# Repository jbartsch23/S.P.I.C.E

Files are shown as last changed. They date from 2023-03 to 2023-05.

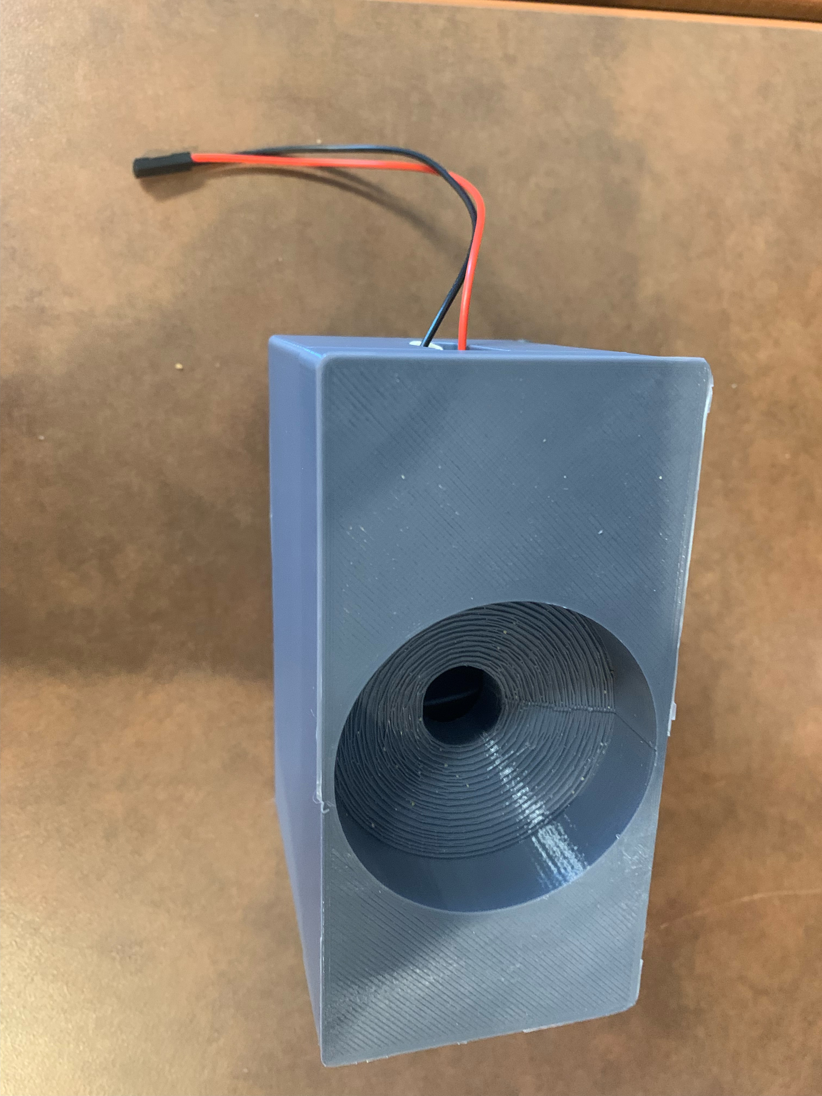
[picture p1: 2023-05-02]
Pictures/housing.jpeg

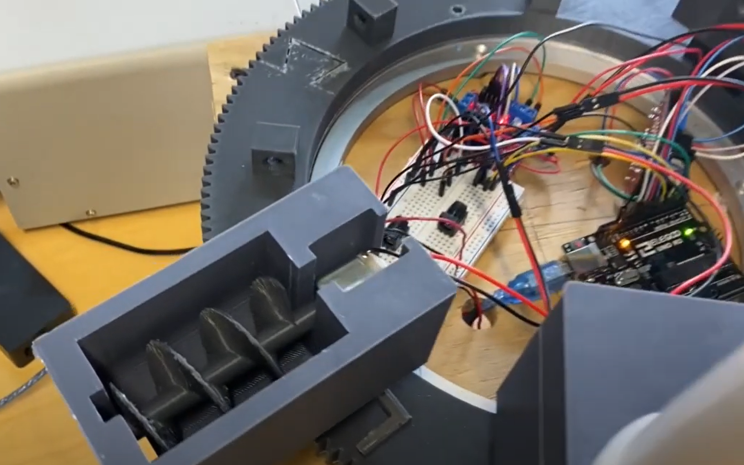
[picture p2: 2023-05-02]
Pictures/circuitry.png

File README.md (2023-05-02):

# S.P.I.C.E.
Directory Guide:
- 3D Models: All inventor files as well as stl files for 3D parts
- Pictures: A collection of close-up pictures of the system
- Presentations: All presentations throughout the semester (Proposal, CDR, Final)
- Reports: All reports throughout the semester (Proposal, CDR, Final)
- TeamMeetings: A collection of every weekly meeting held by Dr.M, TA Karl Ott, and the team
- TeamNotebooks: Notebook scans from each team member throughout the semester
- bin: Directory for all class objects generated from src
- motor_control: The final Arduino code used to operate the SPICE platform
- src: Directory contains all JavaFX and UI elements

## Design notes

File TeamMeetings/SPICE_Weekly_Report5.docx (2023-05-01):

WEEKLY REPORT and MEETING AGENDA

Report #: 5 Project Name: SPICE

Date: 4/4/2023 Prepared by: Carlos Zapata III

Agenda for the meeting

1. Print shop update (Over-Estimated Time)
2. Database progress

Overall accomplishments since last meeting

1. Printed prototype housing at FEDC
2. More prints requested
3. Established database connection

Tasks completed by each team member since last meeting

Task description | Assigned to | Completed?
Received housing and lid printed from FEDC | Carlos | Yes
SQL Server setup, connection between database and UI | JP/Caleb/Carlos | Yes

Plans for next period

1. Improve model designs and send to FEDC to print
2. Finalize database

Task assignment per team member (to be completed before the next meeting)

Task description | Assigned to
Send second set of prints to FEDC | Caleb/Carlos
Finish designing and implement database | JP/Caleb/Carlos
Implement reliable communication between Arduino and Raspberry Pi | Kile/Caleb

Project management status

Minutes from previous meeting

Meeting Minutes (March 29th):

- Print Shop update:
- Dr.M: Tell me about print shop
- Caleb: Originally wanted to print with personal printer, will now be using FEDC to get prints
- Dr.M: One print per day, will take a week, need to get that printed as fast as possible
  - Bottlenecking at 3D printing
- Local SQL Database
- JP: Looking to use local database - Easier to query database
  - Microsoft SQL server
- Dr.M: Demonstrate that system is able to perform recipe function
- Progress with motors and Arduino
- Kile: Motors are working and can be turned off and on with Pi
  - Having trouble with controlling motor speed
- Dr.M: Sounds good
- Troubles with 3D printing
  - Caleb: Taking a long time
  - Dr.M & Karl: Focus on getting functionality with one or two, and then work in parallel
- Dr.M: Might have better 3D printers that work faster
  - Go to shop as soon as possible
- Thinking differently about solutions
- Dr.M: Might want to look for printing outside of A&M
- Dr.M: Keep us updated, think about alternatives

Weekly Report Form. CSCE 483 Computer System Design

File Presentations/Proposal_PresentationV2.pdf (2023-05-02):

A creative solution for assisted cooking

# The Problem

61 Million | 37 Million

01 | Americans Live

100% of People
need to eat

# Needs Statement

### In a country where one in four adults have some form of motor impairment and older adults are more likely to live alone, there’s a serious need for tools that can make tasks easier for motor impaired adults

# The Mission

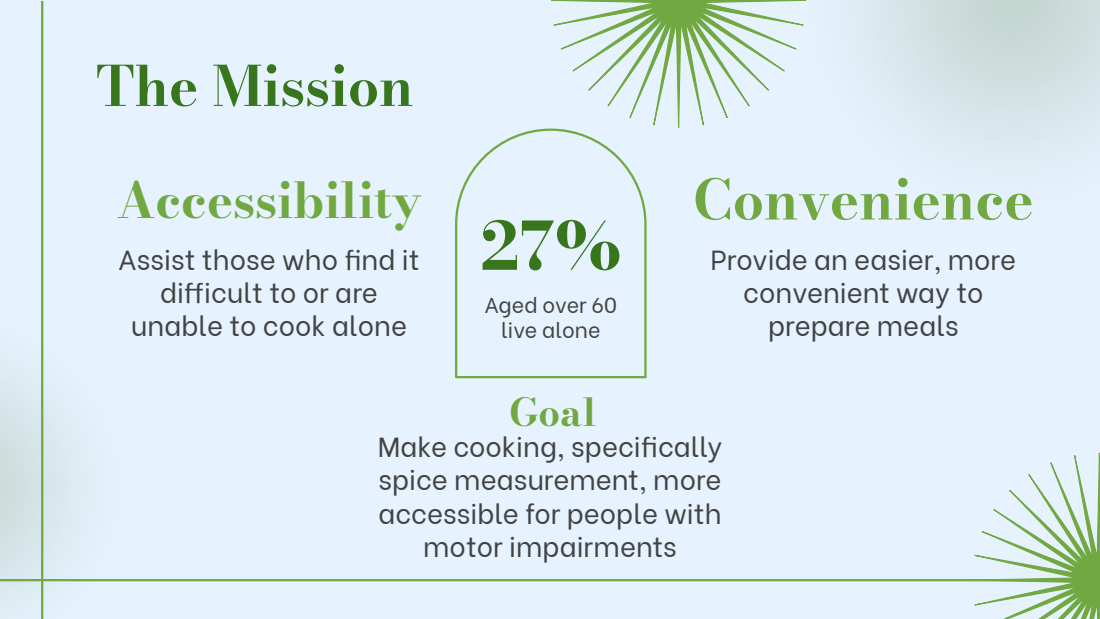
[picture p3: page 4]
Goal; Aged over 60 live alone; Convenience

Accessibility
Assist those who find it
difficult to or are
unable to cook alone

Provide an easier, more
convenient way to
prepare meals

Make cooking, specifically
spice measurement, more
accessible for people with
motor impairments

# Goals and Objectives

Accessibility
S.P.I.C.E. aims to make
cooking accessible for
everyone
Easy Maintenance
S.P.I.C.E. will be easy to use and

Convenience
Providing an exceptionally
convenient way of
preparing meals

# Literature Review

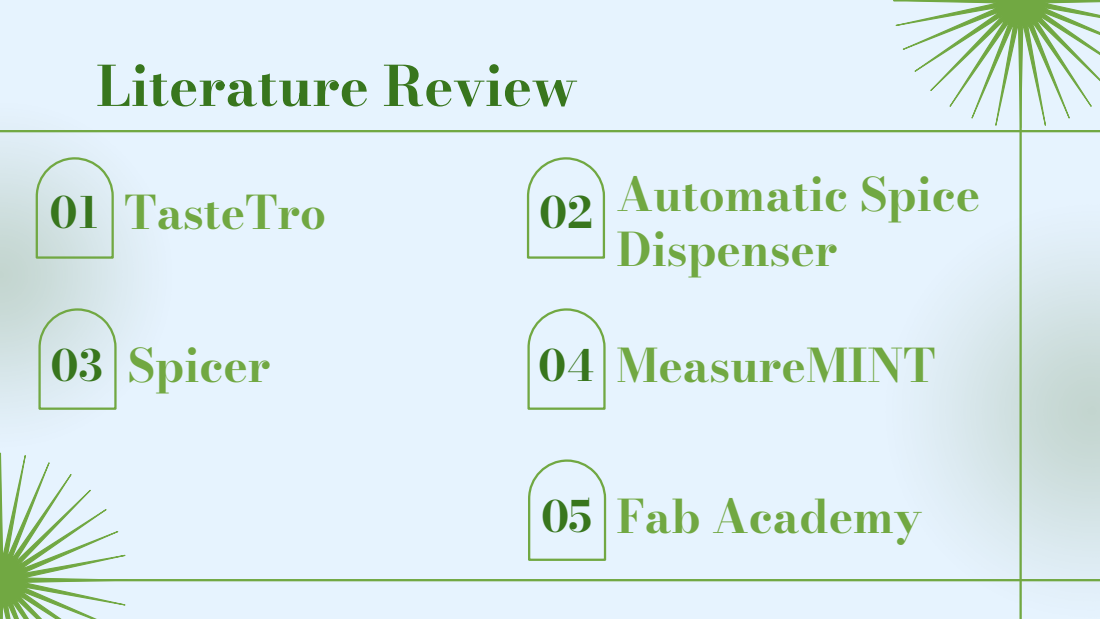
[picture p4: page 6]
TasteTro; Automatic Spice; Dispenser; Spicer; MeasureMINT; 05 Fab Academy

- Commercially advertised since Jan. 2018
- Simple 3-button interface, unique spice storage and distribution
- Operates on predetermined recipes; S.P.I.C.E. intends to consider

- Doesn’t incorporate UI; S.P.I.C.E. intends to

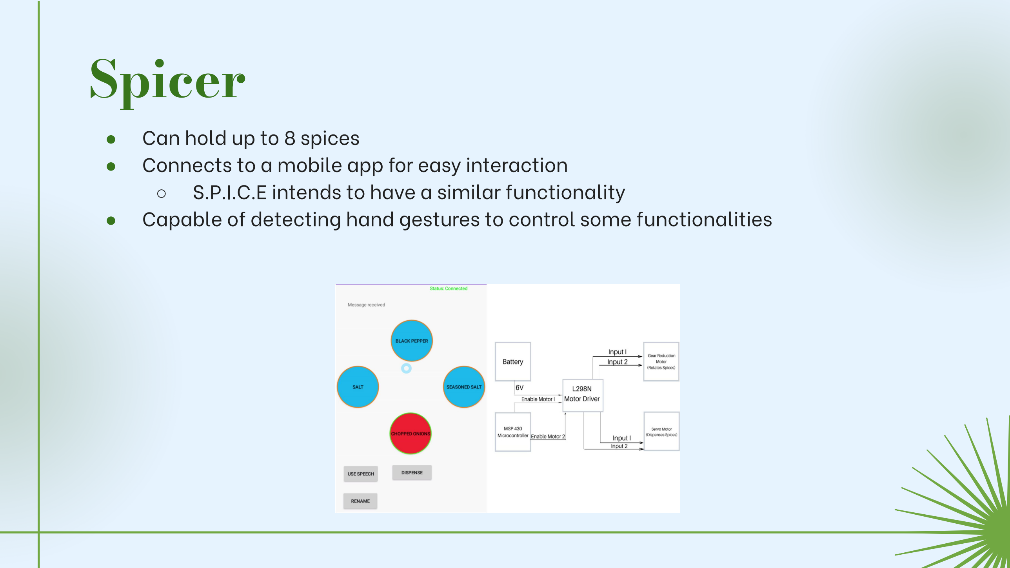
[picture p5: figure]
● Can hold up to 8 spices; Spicer

- Connects to a mobile app for easy interaction
- S.P.I.C.E intends to have a similar functionality
- Capable of detecting hand gestures to control some functionalities

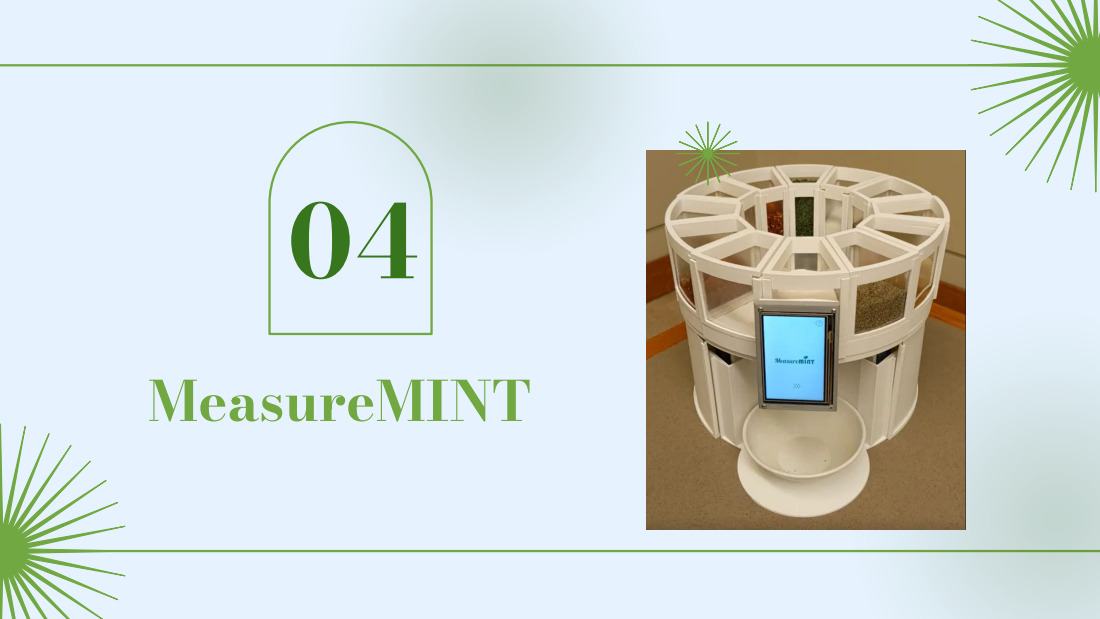
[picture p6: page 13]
MeasureMINT

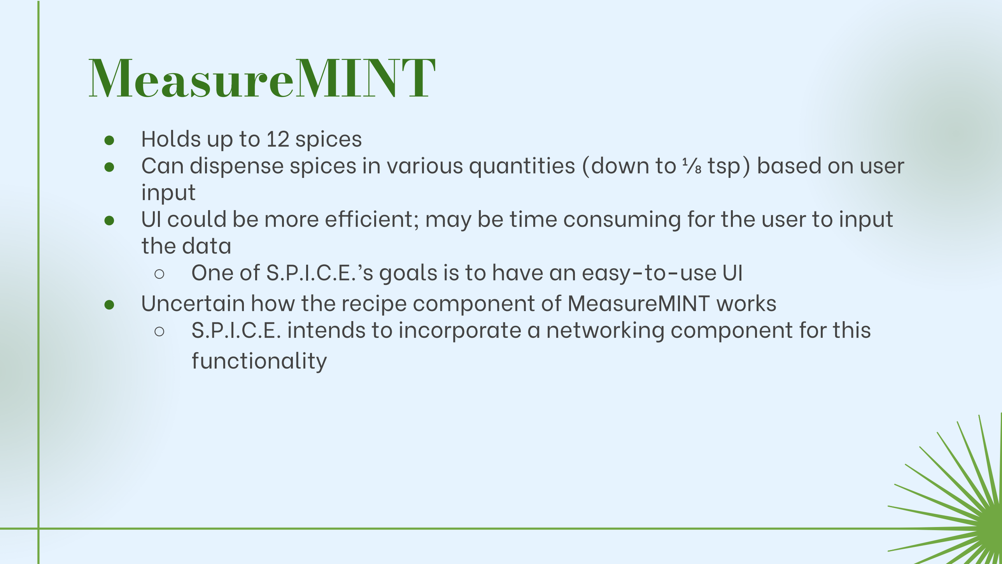
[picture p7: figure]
● Holds up to 12 spices; input; the data; functionality; MeasureMINT

- Can dispense spices in various quantities (down to ⅛ tsp) based on user
- UI could be more efficient; may be time consuming for the user to input
- One of S.P.I.C.E.’s goals is to have an easy-to-use UI
- Uncertain how the recipe component of MeasureMINT works
- S.P.I.C.E. intends to incorporate a networking component for this

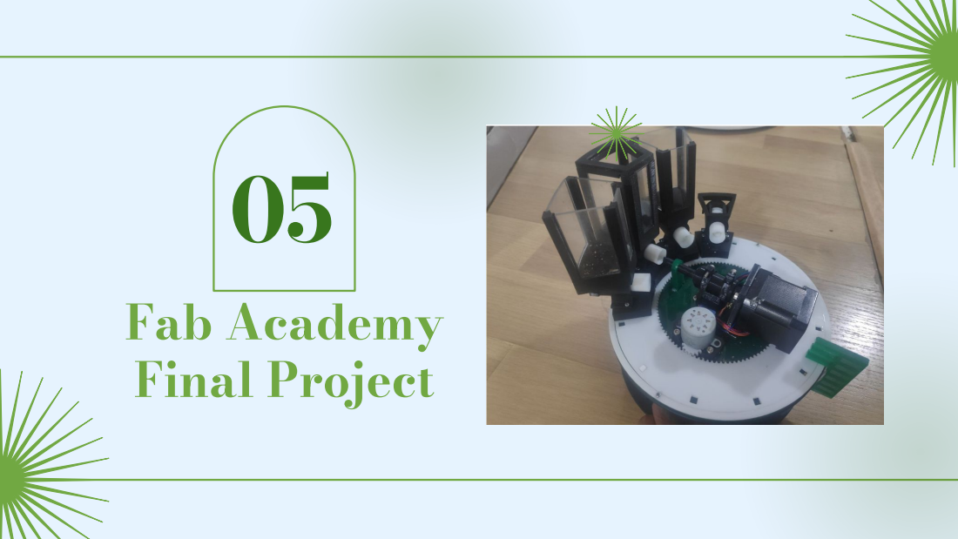
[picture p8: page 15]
Fab Academy Final Project

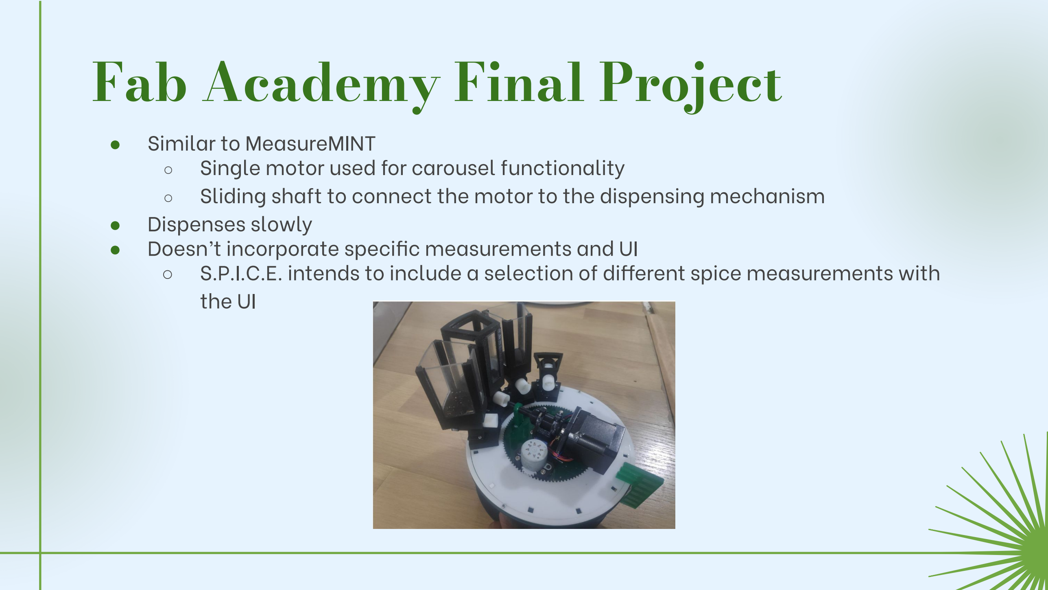
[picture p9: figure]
● Similar to MeasureMINT; ● Dispenses slowly; the UI; Fab Academy Final Project

- Single motor used for carousel functionality
- Sliding shaft to connect the motor to the dispensing mechanism
- Doesn’t incorporate specific measurements and UI
- S.P.I.C.E. intends to include a selection of different spice measurements with

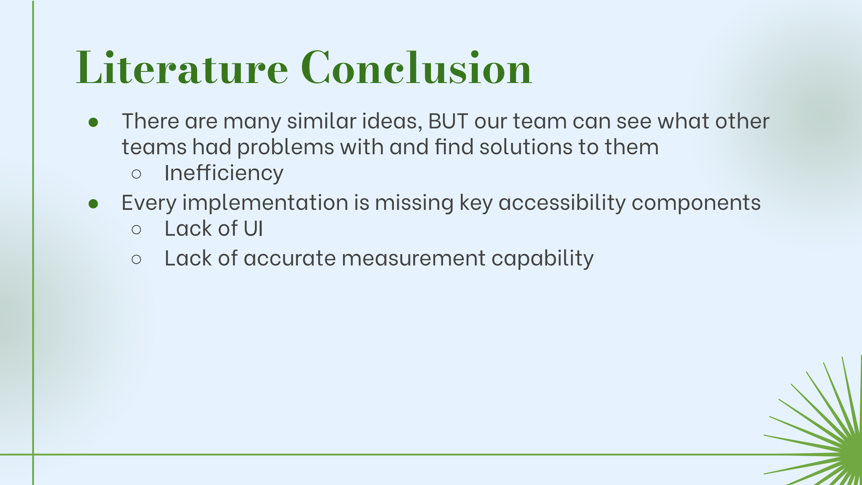
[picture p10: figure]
○ Inefficiency; ○ Lack of UI; Literature Conclusion

### - There are many similar ideas, BUT our team can see what other teams had problems with and find solutions to them

### - Every implementation is missing key accessibility components

### - Lack of accurate measurement capability

# Product Links

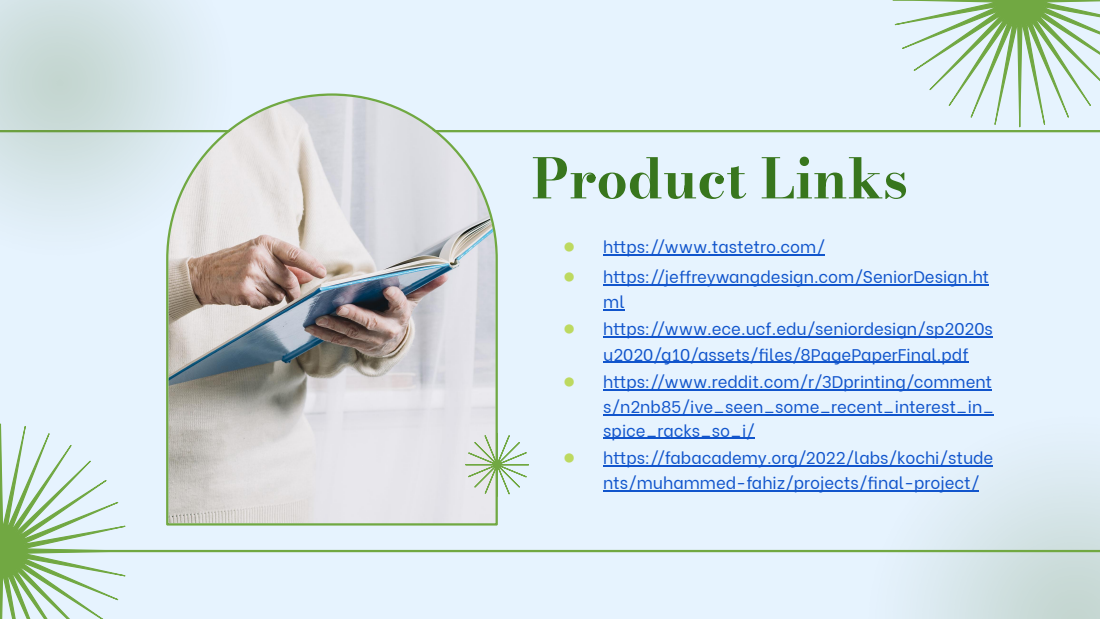
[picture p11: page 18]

● https://www.tastetro.com/
● https://jeffreywangdesign.com/SeniorDesign.ht
● https://www.ece.ucf.edu/seniordesign/sp2020s
u2020/g10/assets/files/8PagePaperFinal.pdf (https://www.ece.ucf.edu/seniordesign/sp2020su2020/g10/assets/files/8PagePaperFinal.pdf)
● https://www.reddit.com/r/3Dprinting/comment
s/n2nb85/ive_seen_some_recent_interest_in_
spice_racks_so_i/ (https://www.reddit.com/r/3Dprinting/comments/n2nb85/ive_seen_some_recent_interest_in_spice_racks_so_i/)
● https://fabacademy.org/2022/labs/kochi/stude
nts/muhammed-fahiz/projects/final-project/ (https://fabacademy.org/2022/labs/kochi/students/muhammed-fahiz/projects/final-project/)

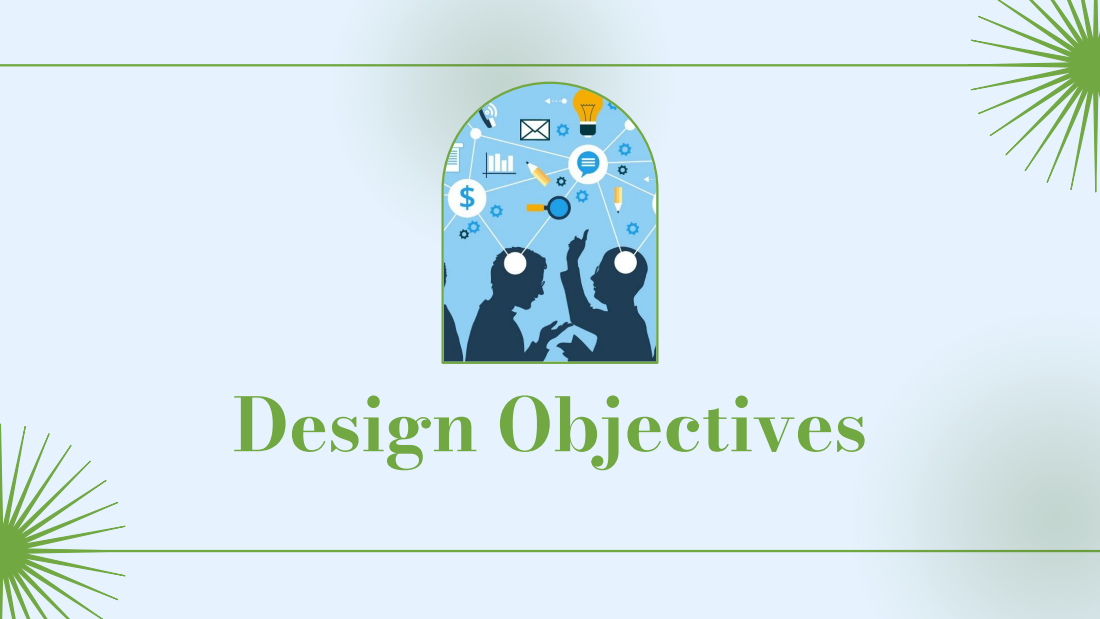
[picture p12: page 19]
Design Objectives

- The system must support at least 4 different spices
- Minimum spice measurement of 1 teaspoon
- The distribution of spices must be accurate to + 0.1 teaspoon
- Larger buttons and bigger text for those with bad eyesight

- The system should fit in a 45x45x45cm box
- The system should feature a mobile application or intuitive interface
- The overall design must have a reasonable level of water resistance
- The system must be able to properly function in the temperature range

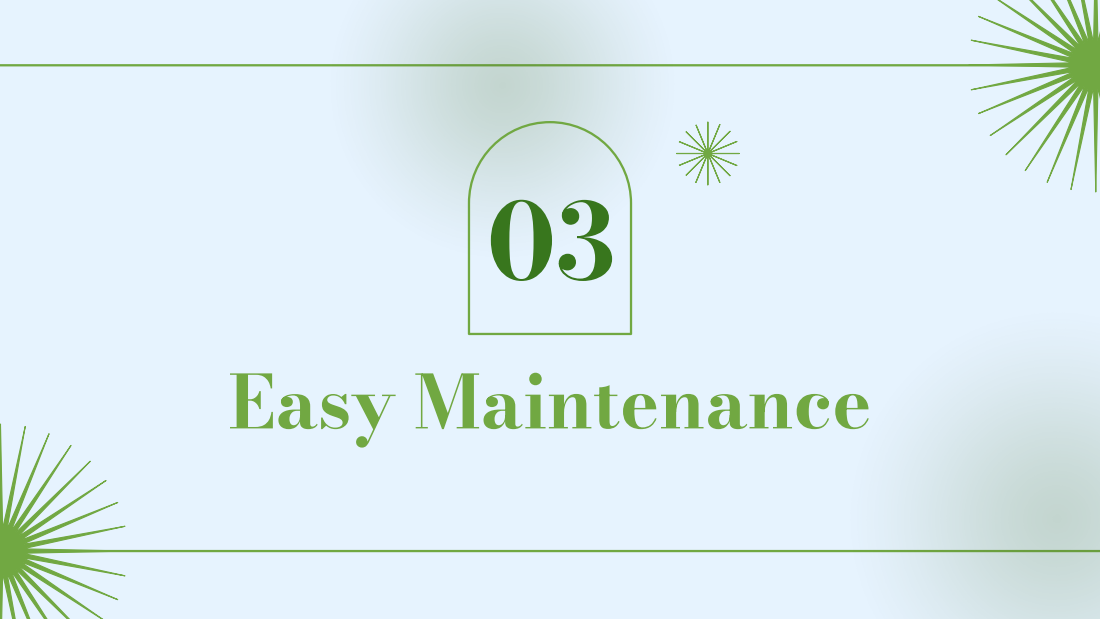
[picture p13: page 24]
Easy Maintenance

- The system must be modular and easy to change spices
- The system must operate efficiently for the user

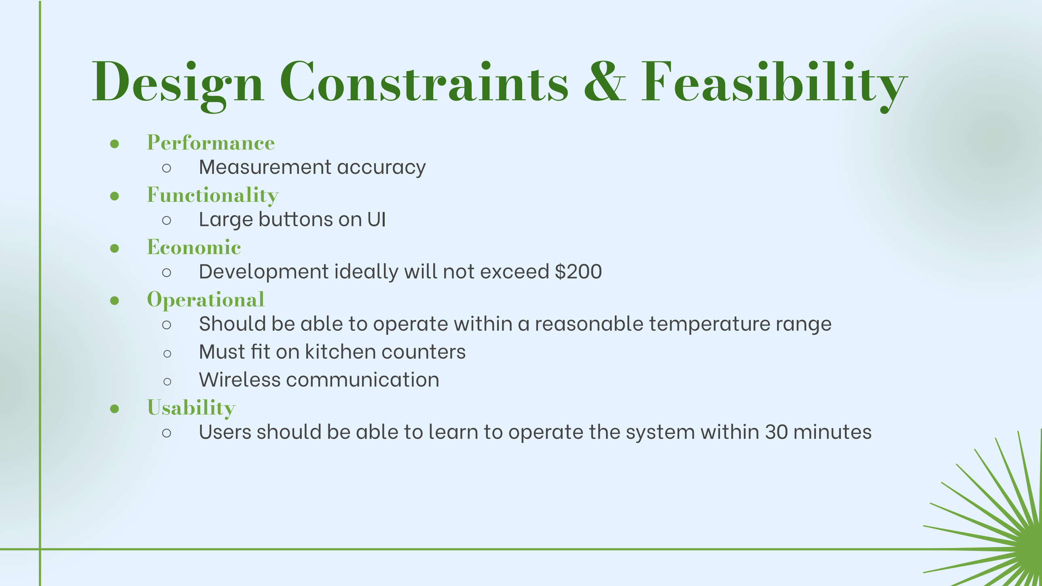
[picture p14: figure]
● Performance ○ Measurement accuracy ● Functionality ○ Large buttons on UI ● Economic; ● Operational; ○ Must fit on kitchen counters ○ Wireless communication ● Usability; Design Constraints & Feasibility

- Development ideally will not exceed $200
- Should be able to operate within a reasonable temperature range
- Users should be able to learn to operate the system within 30 minutes

# Proposed Design/Key Features

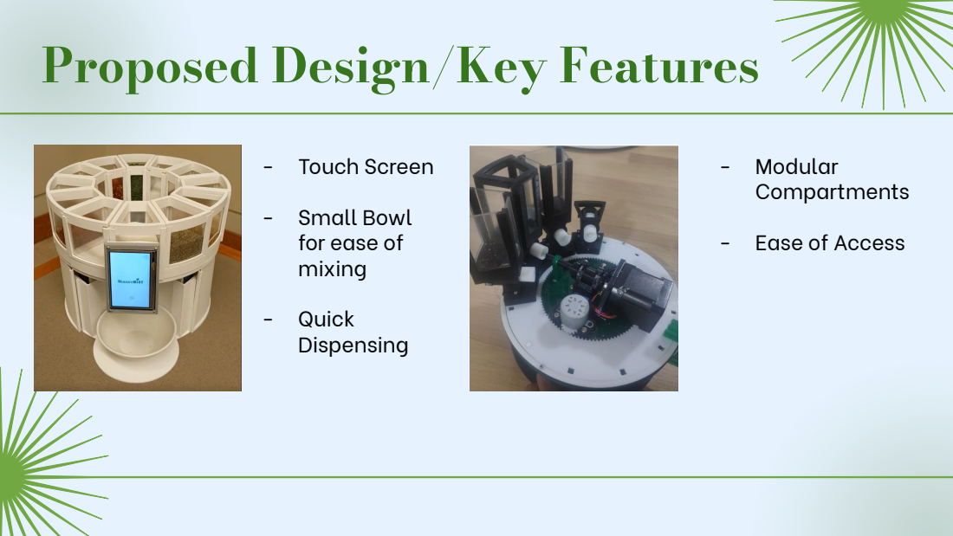
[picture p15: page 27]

- Touch Screen
- Small Bowl
for ease of
mixing
- Quick
Dispensing

- Modular
Compartments
- Ease of Access

# Alternative Solutions

# Rotating

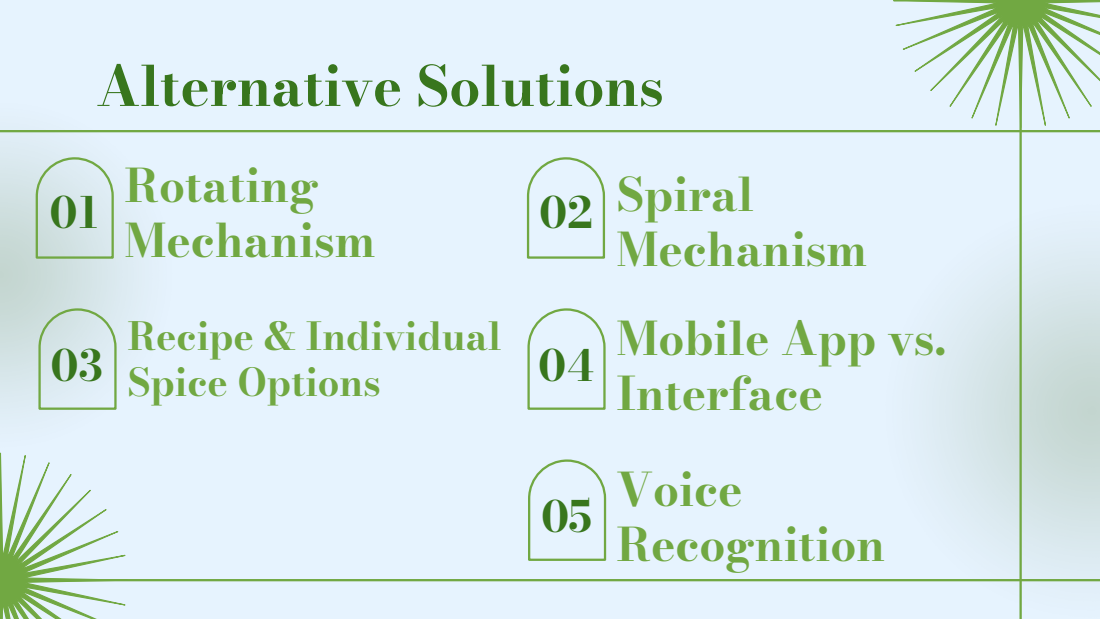
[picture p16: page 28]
Mechanism 01; Spiral; Mechanism; Recipe & Individual; Spice Options 03; Mobile App vs.; Interface 04; Voice Recognition 05

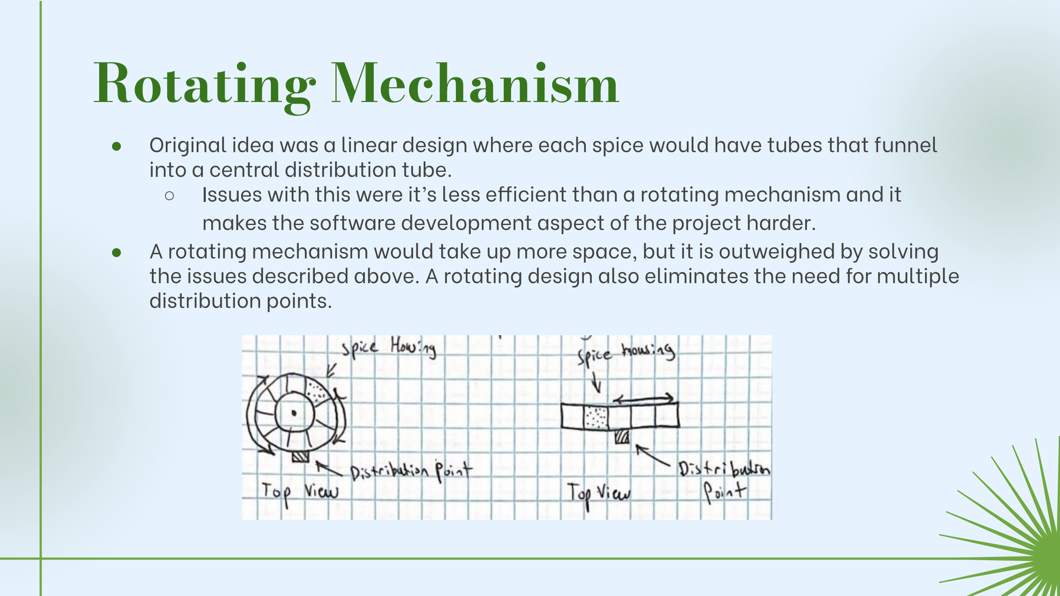
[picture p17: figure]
into a central distribution tube.; distribution points.; Rotating Mechanism

- Original idea was a linear design where each spice would have tubes that funnel
- Issues with this were it’s less efficient than a rotating mechanism and it makes the software development aspect of the project harder.
- A rotating mechanism would take up more space, but it is outweighed by solving the issues described above. A rotating design also eliminates the need for multiple

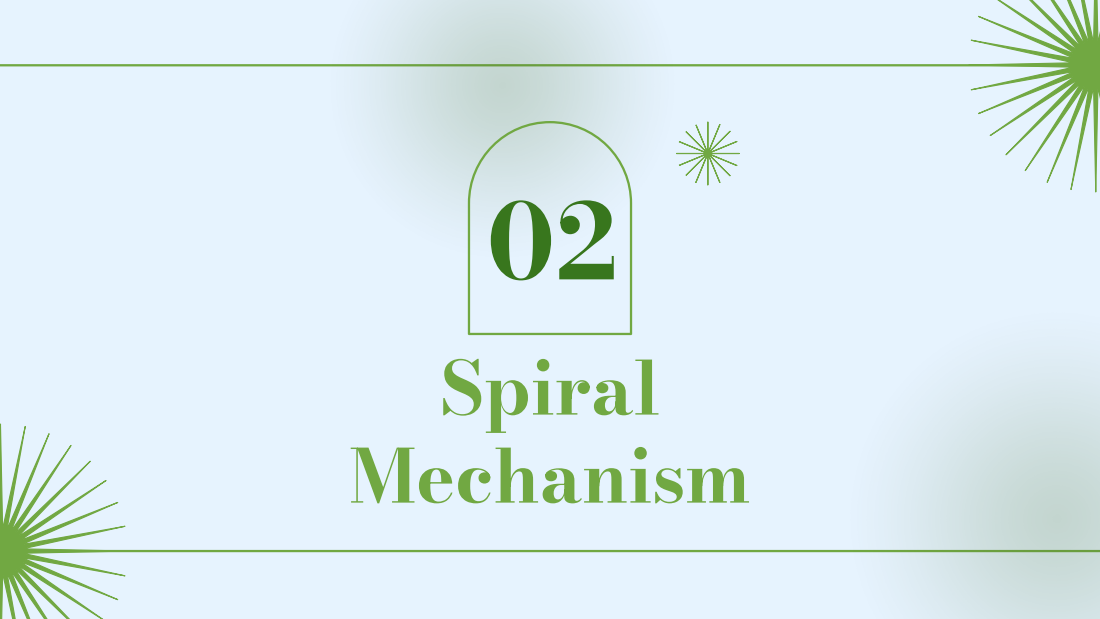
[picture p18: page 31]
Spiral Mechanism

- A spiral mechanism was used in many other projects that provided a similar solution to S.P.I.C.E.
- Corkscrews can be 3D printed, but each spice housing would need one. The budget for the project is already slightly over the limit, and this would push it even further.
- An improved design would be to use a sliding shaft that can connect and retract from each spice housing.
- This reduces the overall number of motors needed
- This idea might be challenging to implement with a rotating spice mechanism.

# Spiral Mechanism

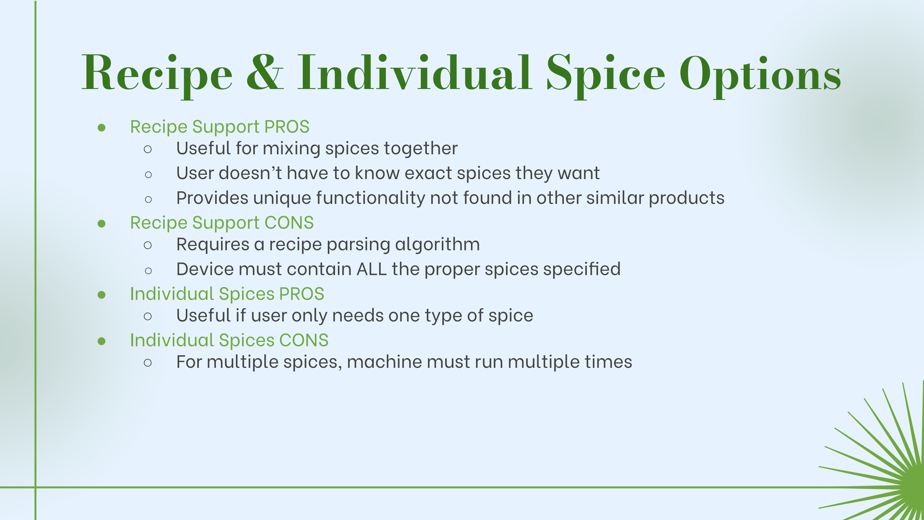
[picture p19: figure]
● Recipe Support PROS ○ Useful for mixing spices together; ● Recipe Support CONS ○ Requires a recipe parsing algorithm; ● Individual Spices PROS; ● Individual Spices CONS; Recipe & Individual Spice Options

- User doesn’t have to know exact spices they want
- Provides unique functionality not found in other similar products
- Device must contain ALL the proper spices specified
- Useful if user only needs one type of spice
- For multiple spices, machine must run multiple times

- Convenience - user doesn’t have to be near device to work it
- Targeted audience might not be able to use smartphones or find them hard
- Deemed harder to implement (requires server hosting)
- Eliminates the need for an external device for controlling
- Deemed easier to implement (doesn’t require server hosting)
- Less convenient to operate, user must be with the machine

- Efficiency; less button-pressing to input data
- Unique in comparison to similar products
- Implementation (may require integration of various API’s, voice recognition libraries, ML, and the usage of other tools or technologies)
- Doesn’t have much benefit for the deaf (can’t speak into the system)

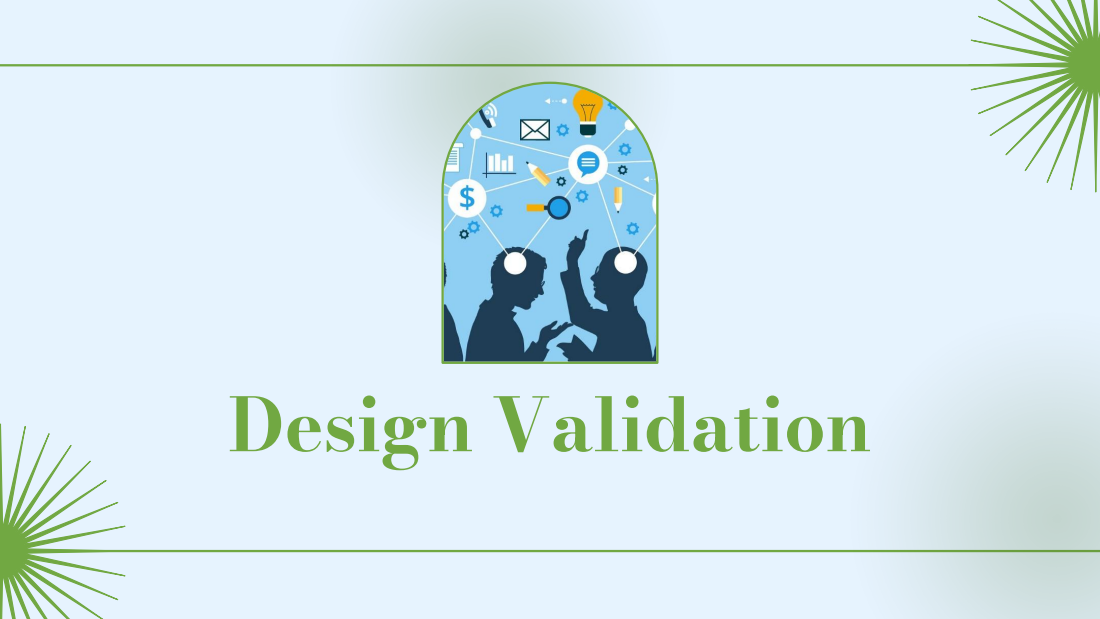
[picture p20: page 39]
Design Validation

# Validation Components

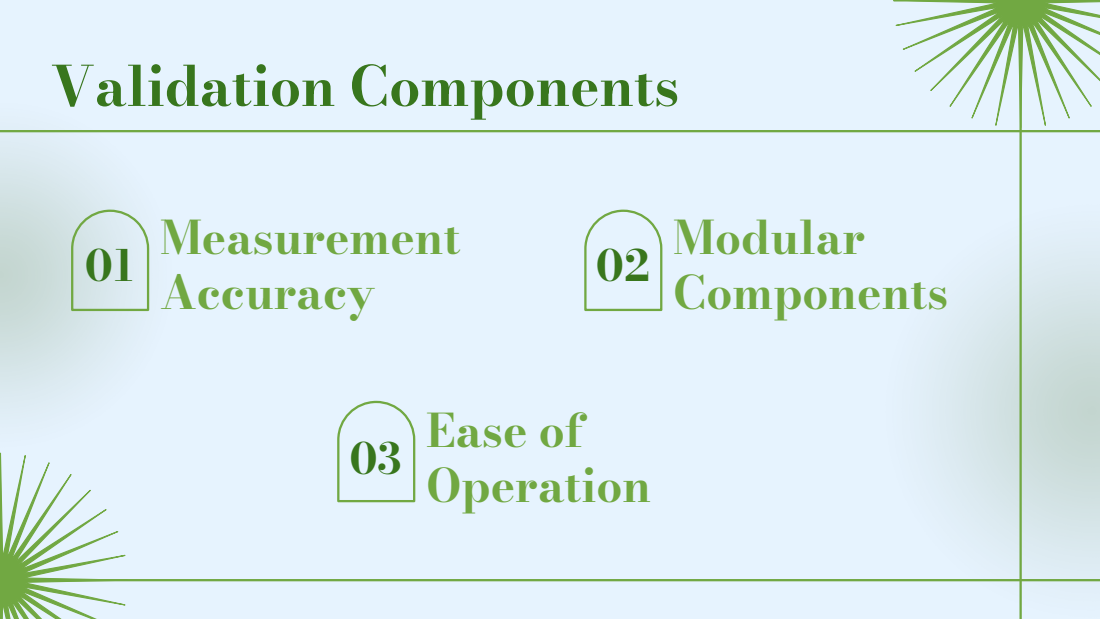
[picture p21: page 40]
Measurement Accuracy 01; Ease of Operation 03; Modular Components 02

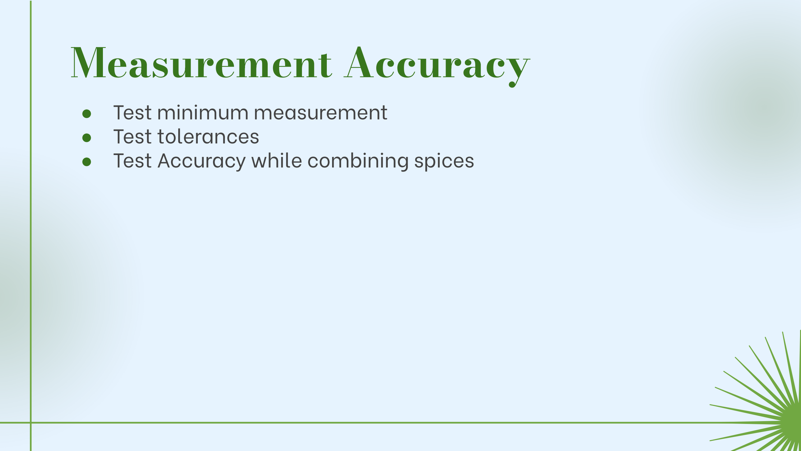
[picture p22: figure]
● Test minimum measurement ● Test tolerances ● Test Accuracy while combining spices; Measurement Accuracy

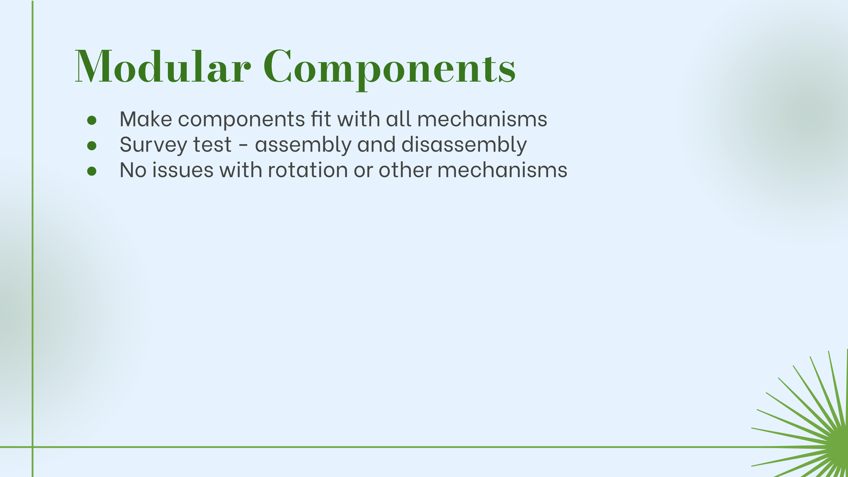
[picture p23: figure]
Modular Components

### - Make components fit with all mechanisms - Survey test - assembly and disassembly - No issues with rotation or other mechanisms

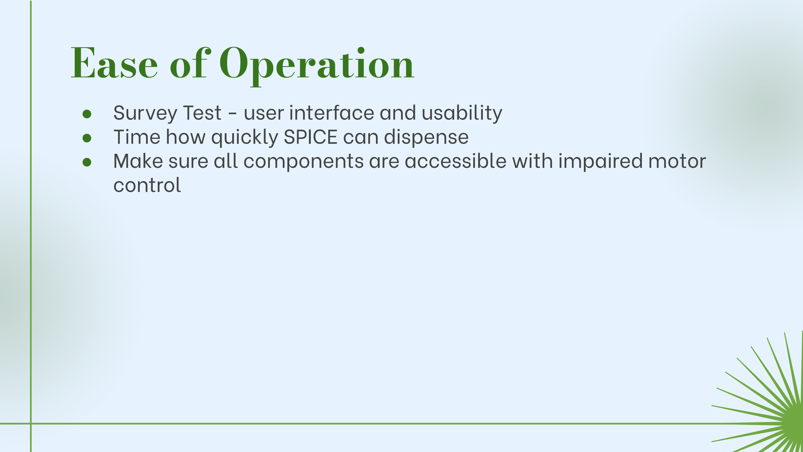
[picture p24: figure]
● Time how quickly SPICE can dispense; control; Ease of Operation

### - Survey Test - user interface and usability

### - Make sure all components are accessible with impaired motor

# Economic Analysis

# Economical

- S.P.I.C.E. will be highly marketable to the community
- Similar products contain features that other products don’t have
- S.P.I.C.E. intends to take inspiration from those products and integrate those features to become one working prototype
- Simplifies the difficult cooking process for elderly people living alone and those who are motor disabled
- Moderate cost since the product relies heavily on hardware and no resources are needed for the software besides the touchscreen

# Economical Viability

- Many parts are available from multiple vendors.
- Makes it easier to replace parts if anything happens to them.
- Repairs on the device should be fairly straightforward if designed properly.
- The Raspberry Pi and Arduino are the only valuable components that will be hard to replace in the event that one or both of them break.

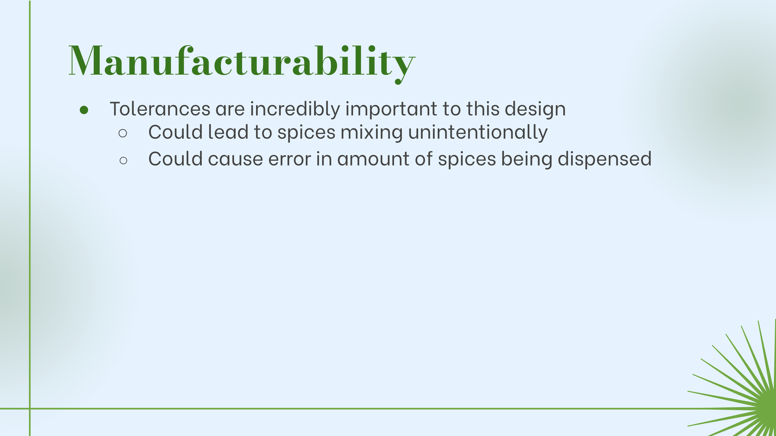
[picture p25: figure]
Manufacturability

### - Tolerances are incredibly important to this design - Could lead to spices mixing unintentionally - Could cause error in amount of spices being dispensed

- S.P.I.C.E. is a product that is expected to encourage cooking in the sense that it simplifies the process for all demographics and not just motor disabled people
- Makes cooking less tedious for people since it eliminates the need to manually measure out spices when seasoning food
- Expected to greatly improve the quality of food and reduce the amount of error in seasoning food
- Promotes the well-being of people by helping them produce high quality food

# Societal Analysis

- To avoid personal injuries, the S.P.I.C.E will be designed in such a way that hides all critical and potentially dangerous components within its container. Not only does this protect the various components from outside damage, but also protects the user when interacting with the device.
- When building the device, we will ensure that all components are fastened tightly and neatly organized within the container to avoid potential breakdown of the device which could endanger the user.

# Safety Analysis

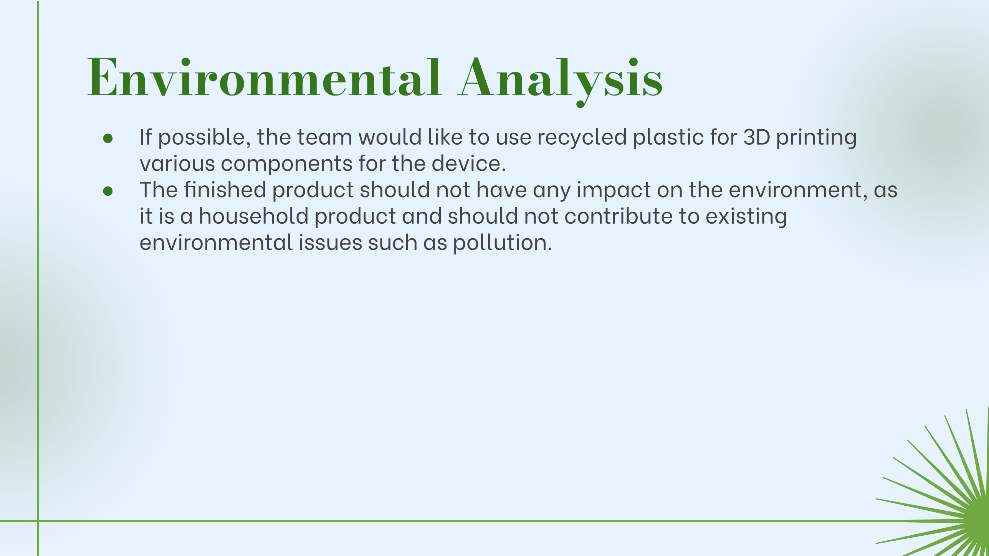
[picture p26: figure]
various components for the device.; environmental issues such as pollution.; Environmental Analysis

- If possible, the team would like to use recycled plastic for 3D printing
- The finished product should not have any impact on the environment, as it is a household product and should not contribute to existing

Team Structure & Management

# The Team

Role | Member(s)
Project Manager | | Carlos Zapata III

Mechanical Design

| ● Component Modeling ● Material Acquisition ● Hardware Placement | ● Caleb Herrera, Carlos Zapata III ● Carlos Zapata III ● Caleb Herrera

Software Design

| ● UI Designer ● Microcontroller Specialist ● Hardware Networking | ● JP Bartsch ● Kile Zimmermann ● JP Bartsch, Kile Zimmermann
Validation Lead | | JP Bartsch

# Thanks

Do you have any questions?

CREDITS: This presentation template was
created by Slidesgo, (http://bit.ly/2Tynxth) including icons by Flaticon (http://bit.ly/2TyoMsr)
and infographics & images by Freepik (http://bit.ly/2TtBDfr)

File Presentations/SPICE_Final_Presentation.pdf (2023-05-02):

Salty Seniors

Final Design Showcase

A creative solution for assisted cooking

# The Problem

61 Million | 37 Million

with Disabilities; 27% of Americans over 60 live alone; Americans are Motor Impaired

01 | Americans Live

100% of People
need to eat

# Goals and Objectives

01 Accessibility; 02 Convenience; 03 Easy Maintenance

# Design Requirements

# Accessibility

- Supports up to 8 spices; Convenience; Easy Maintenance

- Simple and intuitive interface (Time requirement)
- Accurate dispensing, down to 土0.1 teaspoon

- Product is easy to move (Fits in 45cm x 45cm x 45cm)
- S.P.I.C.E. dispenses within time frame (at most 1 min)

- Components can be disassembled
- Individual components can be washed
- Motors can be replaced with relative ease

Design Alternatives & Changes

Design

- Container change (Custom -> Spice Bottle)
- Bearing gear (Split into two pieces for printability)
- Number of motors (Single Motor -> Motor with each housing)
- Battery power for motor driver (9V power supply -> 12V power supply)
- Recipes (Web Scraping -> on-board memory)
- Updated budget (Added cost of 3D printing and more DC motors)

Base & Bearing Table

Bearing Gear

# Number of Motors (Housing Design)


data with their respective spices; recipes shown on the UI; Recipes

- Instead of an online search feature, S.P.I.C.E. uses a built-in class to store recipe
- No need for a keyboard to be implemented; user can just select from a list of

# Final Budget

Item | Quantity | Cost Per Item | Total Cost
Raspberry Pi Touch Screen | 1 | $63.99 | $63.99
Brown PLA 1.75mm (1kg) | 2 | $19.99 | $39.98
4 Pack L298N Motor Controller | 1 | $11.59 | $11.59
Bearing Table | 1 | $20.82 | $20.82
20 kg Servo Motor | 1 | $12.99 | $12.99
6 Pack DC Motor | 1 | $8.99 | $8.99
Stepper Motor | 1 | $12.99 | $12.99
3D Printing Services ($/g) | 982 | $0.03 | $29.47
Total | $200.82

System Specifications

● Touch Screen; ● Raspberry Pi; ● Arduino; UI ● Motors; Hardware

- Main point of contact for users; displays UI
- Process human interactions and send data to the arduino
- Controller for servos and motors throughout the device; receives instructions from Raspberry Pi on which motors to activate depending on user input from
- Distribution motor for each housing component

● User Interface ○ User can choose between two different options for dispensing ○ Spices; User can manually measure; quantities of spices in tsp with the use of a slider ○ Recipes; spices; Software

■ Use a class to store recipes and their

Circuit Diagram; Two Motor Drivers: ● Stepper Motor ● Housing Motors
User Interface

● Landing Page ○ Spices; Measurements; ○ Recipes; ○ Mappings; UI Design

■ | Use recipes class to store recipes and their spices
■ | View spices and their assigned housings ● Each housing represented with an integer value

Mapping Page

Confirmation Page

○ Housings ○ Lids ○ Spirals ○ Gears; environmental issues such as pollution.; Environmental Analysis

- The team used PLA for 3D printing various components for the device.
- The finished product does not have any impact on the environment, as it is a household product and should not contribute to existing

● Exposed Circuitry; ● Food Contact with Materials ○ PLA is deemed safe for food contact; ● Requires a Stronger Power Source; ○ Adjustable Power Supply; ○ Ideally, use a wall outlet

- All hardware is placed on top of the wooden frame without a cover ■ Potentially make a dome to cover up components
- Potential hazard of putting microplastics in food
- 9V battery -> not enough power for the entire system

■ 12V & 2A -> enough to power entire system reliably

# Environmental and Health/Safety Concerns

### Socially - This product is designed to be affordable and easily

accessible to all people with a focus on the elderly.
Politically - This product doesn’t currently have internet capabilities,

### but later iterations might. Models with access to the internet would also need to be secured similarly to other IOT devices to protect

users data.

### Ethically - Production emissions, plastic waste, and recyclability will need to be taken into consideration if this product became

commercially available.

# Social, Political, Ethical Concerns

# Economic Analysis

# Economical

Viability 01; Sustainability; 03 Manufacturability

- S.P.I.C.E. will be highly marketable to the community
- Similar products contain features that other products don’t have
- S.P.I.C.E. took inspiration from those products and integrated those features to become one working prototype
- Simplifies the difficult cooking process for elderly people living alone and those who are motor disabled
- Moderate cost since the product relies heavily on hardware and no resources are needed for the software besides the touchscreen

# Economical Viability

Sustainability

- Many parts are available from multiple vendors.
- Makes it easier to replace parts if anything happens to them.
- Repairs on the device should be fairly straightforward if designed properly.
- The Raspberry Pi and Arduino are the only valuable components that will be hard to replace in the event that one or both of them break.

spices inside housings; Manufacturability

### - Tolerances are incredibly important to this design - Could lead to spices mixing unintentionally - Friction between spirals and spices was an issue that we encountered; had to dispense spices without large amounts of

- UI successfully displays on touchscreen with correct proportions and button responses
- Motors spin when housing is empty and when small amounts of spice have been loaded
- Stepper motor and individual DC motors correctly respond to serial communications
- Minimum of 12V required for stepper motor to rotate the main gear
- Adjustments had to be made to one of the housing lids; part of the motor shaft was most likely being blocked by it

# Test Results

# Thanks


Do you have any questions?

CREDITS: This presentation template was
created by Slidesgo, (http://bit.ly/2Tynxth) including icons by Flaticon (http://bit.ly/2TyoMsr)
and infographics & images by Freepik (http://bit.ly/2TtBDfr)

1. J. Ausubel, “Older people are more likely to live alone in the U.S. than elsewhere in the world,” Pew Research Center,
2. C. Martinez, “Disability statistics in the US: Looking beyond figures,” Inclusive City Maker, 21-Nov-2022. [Online]. Available:

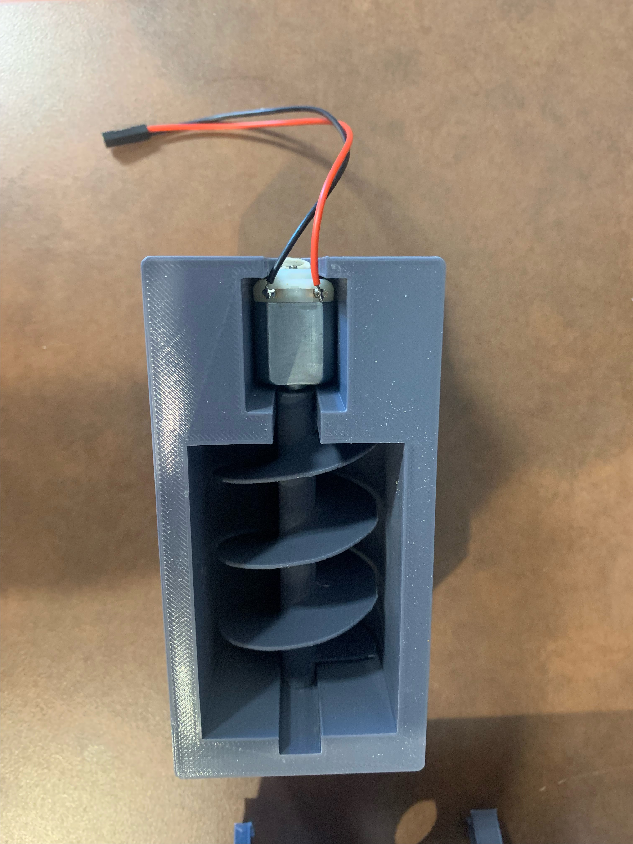
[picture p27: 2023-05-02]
Pictures/housing_without_lid.jpeg

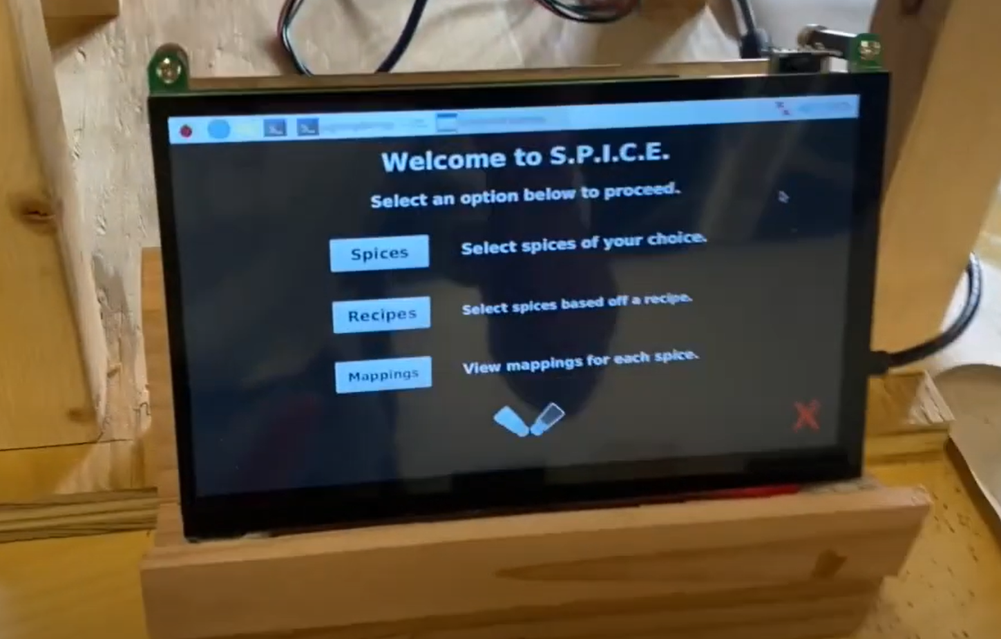
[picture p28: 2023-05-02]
Pictures/touch_screen.png

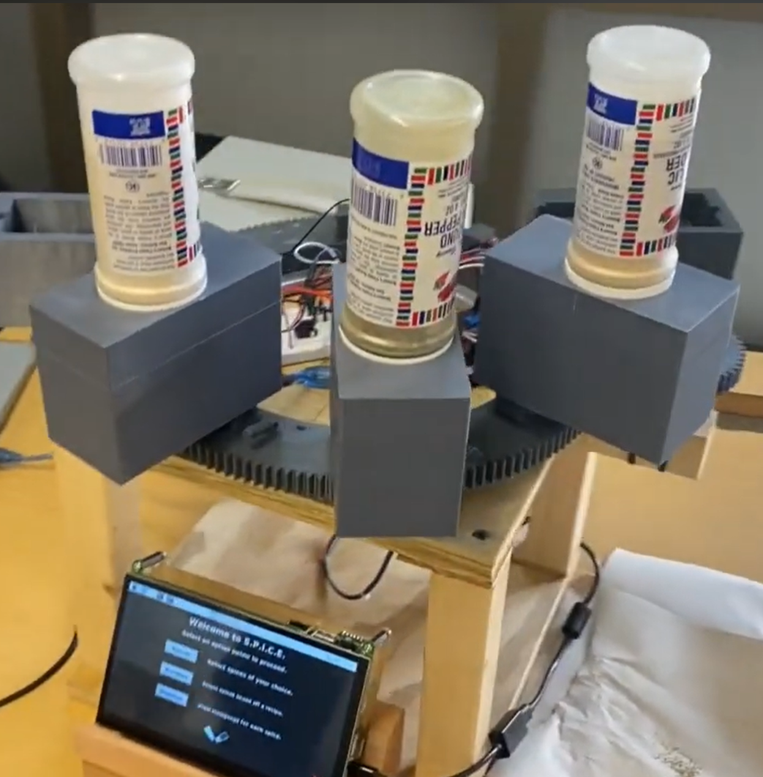
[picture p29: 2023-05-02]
Pictures/spice_system.png

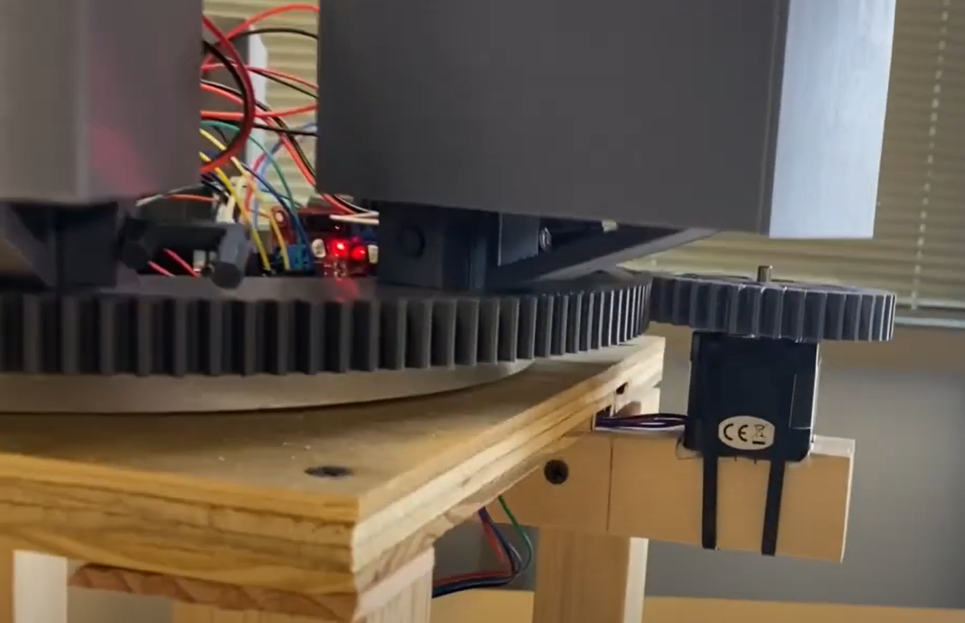
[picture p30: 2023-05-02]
Pictures/stepper_motor_pic.png

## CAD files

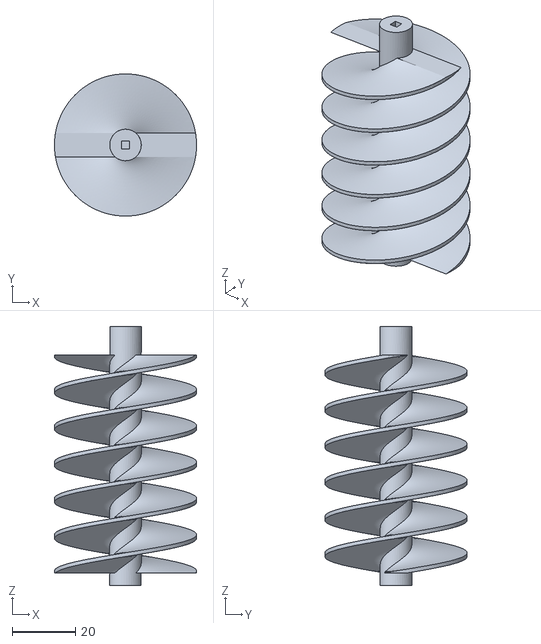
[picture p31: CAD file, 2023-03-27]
3D Models/stls/spiral.stl
45.0 x 45.0 x 82.0

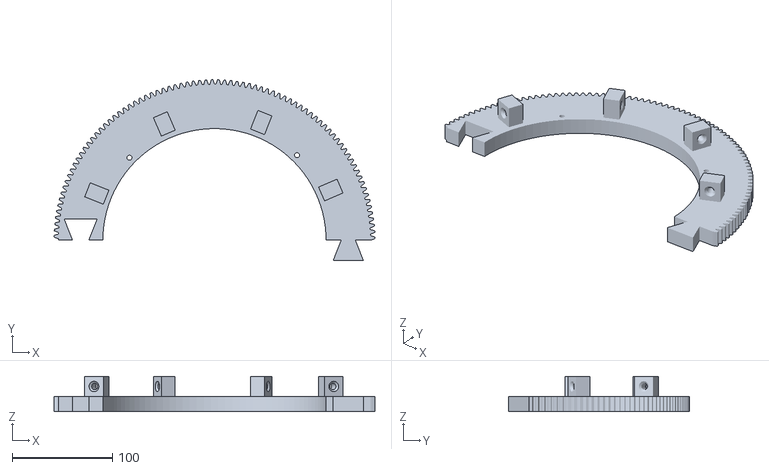
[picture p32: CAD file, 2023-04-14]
3D Models/Version1/stls/BearingGearMk2.stl
320.0 x 180.0 x 35.0

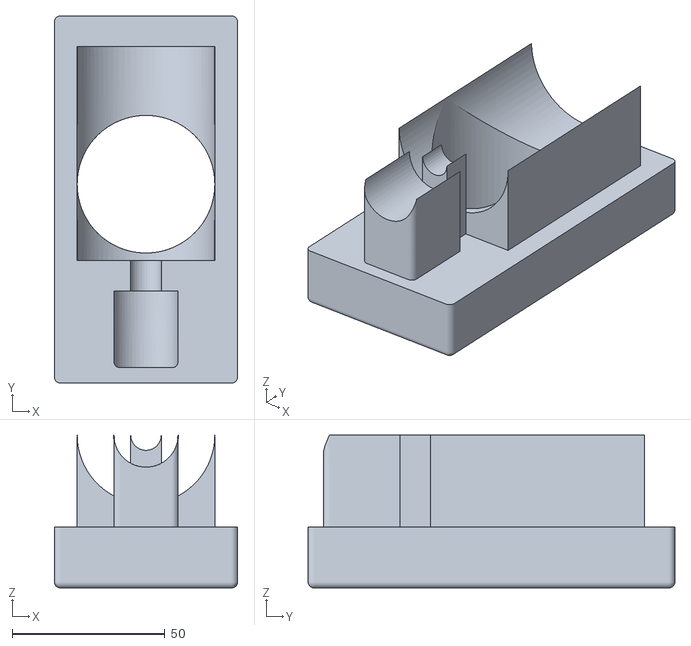
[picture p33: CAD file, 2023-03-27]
3D Models/stls/housing_lid_V2.stl
60.0 x 120.0 x 50.0

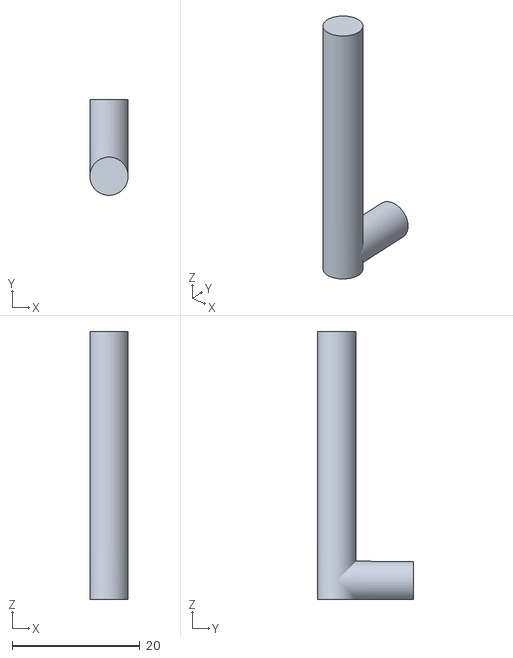
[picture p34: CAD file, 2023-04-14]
3D Models/Version1/stls/Connector.stl
6.00 x 15.0 x 42.0

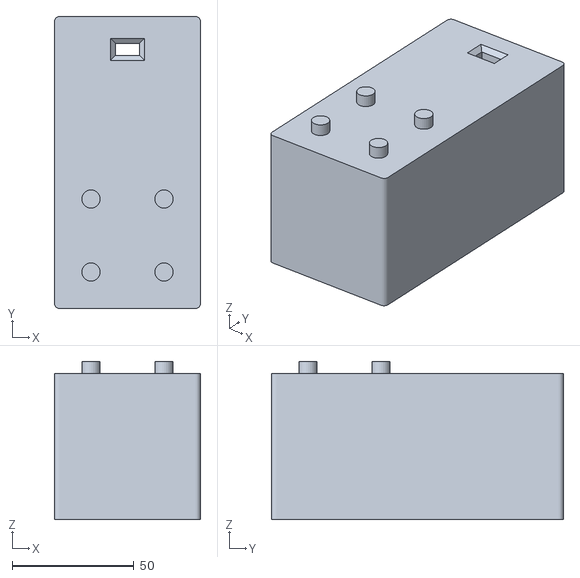
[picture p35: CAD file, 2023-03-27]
3D Models/stls/housing_V2.stl
60.0 x 120.0 x 65.0

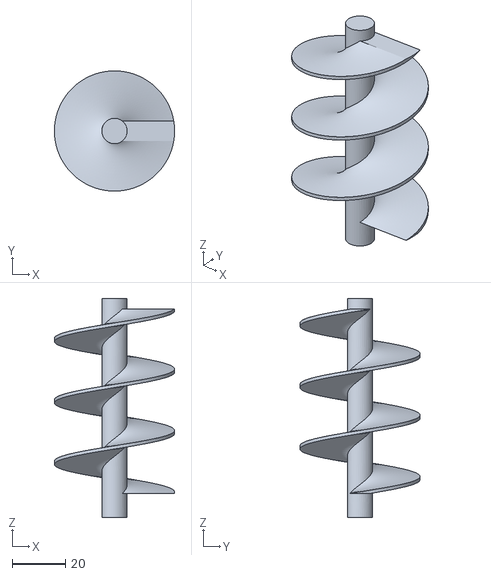
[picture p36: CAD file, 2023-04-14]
3D Models/Version1/stls/spiralV2.stl
45.0 x 45.0 x 82.0

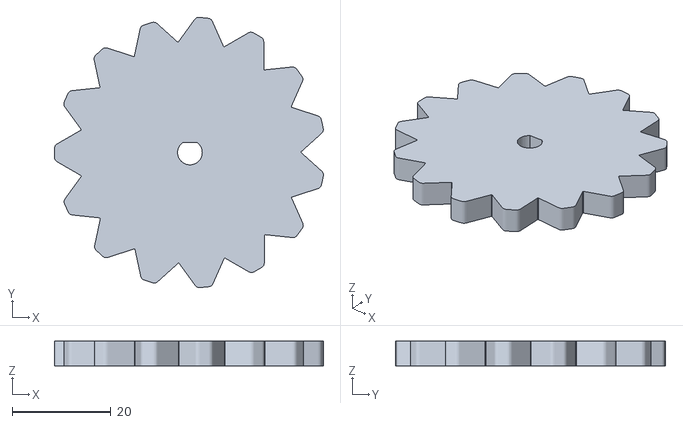
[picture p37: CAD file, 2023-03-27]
3D Models/stls/motor_gear.stl
54.4 x 54.7 x 5.00

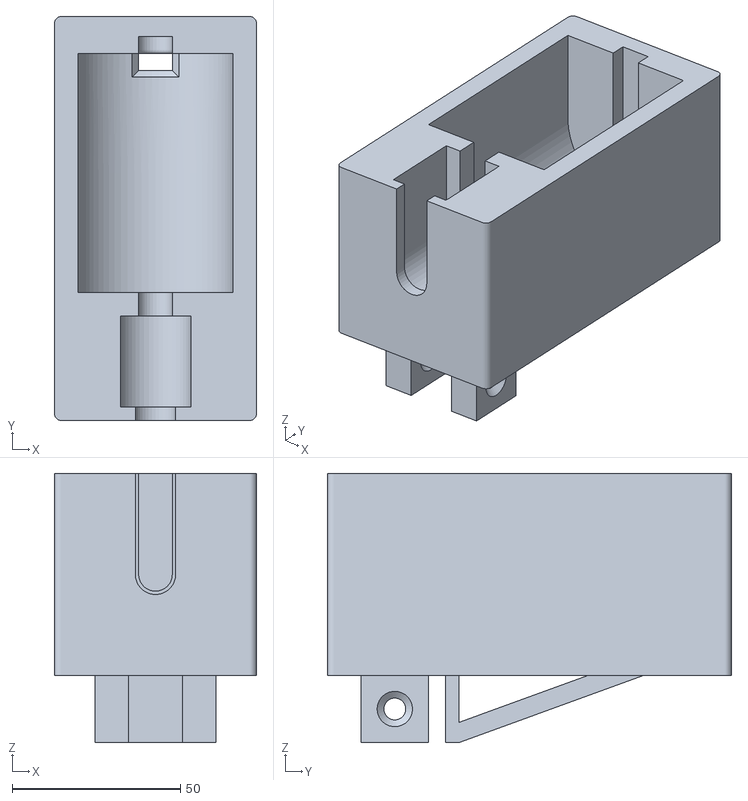
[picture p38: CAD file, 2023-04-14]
3D Models/Version1/stls/housing_V4.stl
60.0 x 120.0 x 80.0

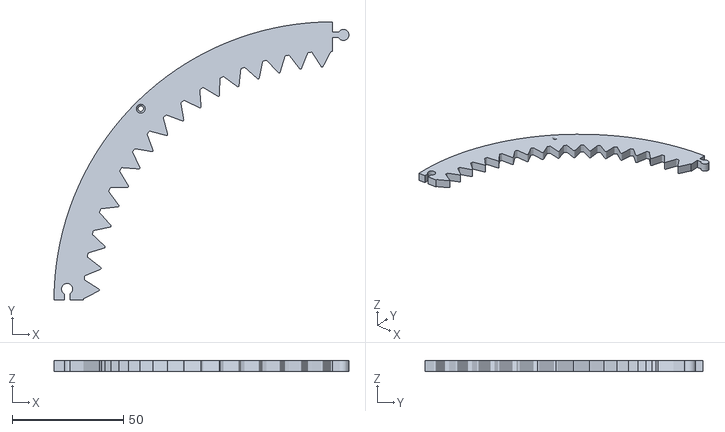
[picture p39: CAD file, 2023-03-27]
3D Models/stls/quarter_bearing_gear.stl
132.5 x 125.0 x 5.00

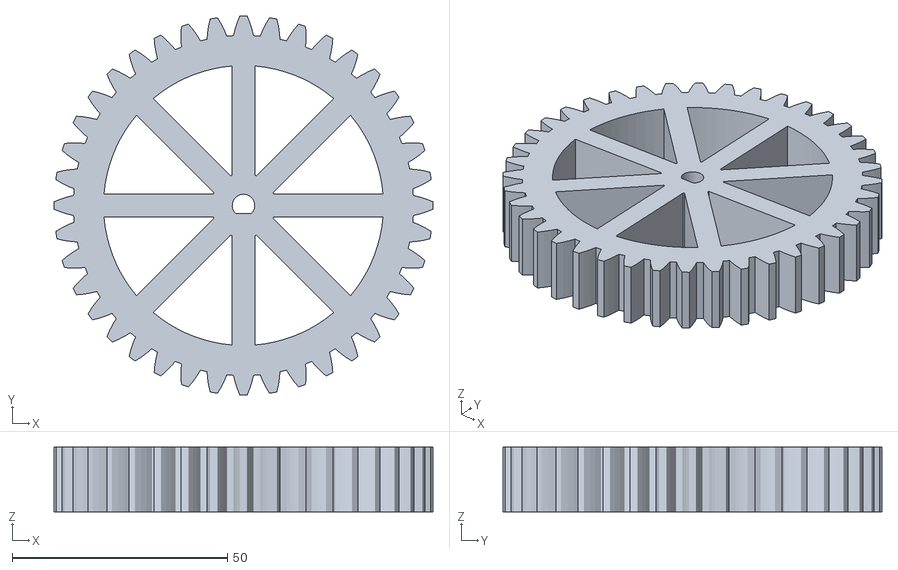
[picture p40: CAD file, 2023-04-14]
3D Models/Version1/stls/motor_gearMk3.stl
88.0 x 88.0 x 15.0

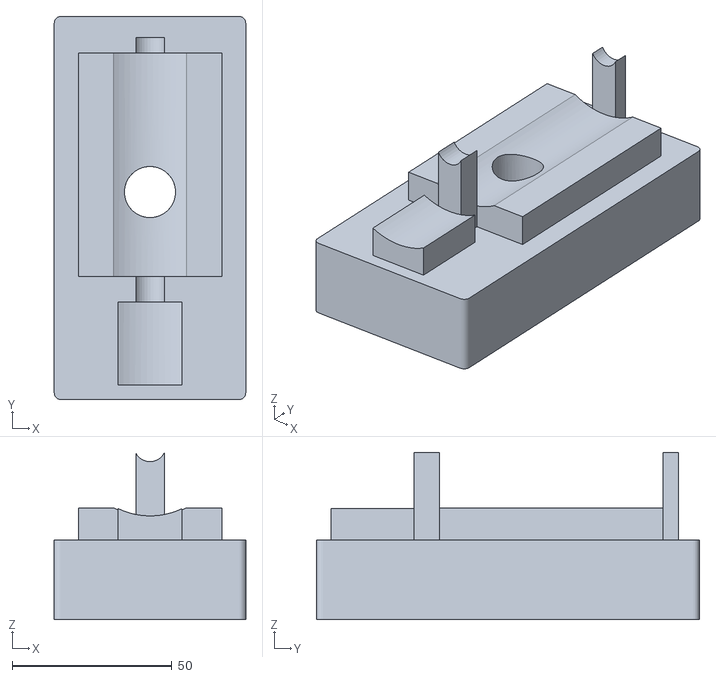
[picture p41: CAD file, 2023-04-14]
3D Models/Version1/stls/housing_lid_V3.stl
60.0 x 120.0 x 52.4

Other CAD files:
3D Models/Version1/stls/housing_V3.stl
3D Models/DCMotor.ipt
3D Models/DCMotorAssembly.iam
3D Models/DCMotorShaft.ipt
3D Models/FiestaSpiceContainer.ipt
3D Models/NewBearingGear.ipt
3D Models/OldVersions/DCMotorAssembly.0002.iam
3D Models/OldVersions/bearing_table.0004.ipt
3D Models/OldVersions/chamber_assembly.0009.iam
3D Models/OldVersions/dcmotor_housing.0011.ipt
3D Models/OldVersions/dcmotor_housing_lid.0004.ipt
3D Models/OldVersions/housing_V3.0021.ipt
3D Models/OldVersions/housing_lid_V3.0004.ipt
3D Models/OldVersions/spiral.0017.ipt
3D Models/OldVersions/spiralV2.0004.ipt
3D Models/Version1/Assembly1.iam
3D Models/Version1/BaseAssemblyMk1.iam
3D Models/Version1/BaseMk1.ipt
3D Models/Version1/BearingGearMK1.ipt
3D Models/Version1/BearingGearMk2.ipt
3D Models/Version1/BearingTable.iam
3D Models/Version1/BearingTableGear.ipt
3D Models/Version1/Connector.ipt
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

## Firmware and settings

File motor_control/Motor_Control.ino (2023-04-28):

#include <Servo.h>
#include <Stepper.h>

//TODO: REMOVE SERVO CODE -> ONLY USING STEPPER & DC MOTORS

int pos = 0;
Servo servo;

const int stepsPerRevolution = 100;
Stepper myStepper(stepsPerRevolution, 8, 9, 10, 11);

//TODO: FIGURE OUT SYSTEM FOR IMPLEMENTING MULTIPLE DC MOTORS 
int in1 = 3;
int in2 = 4;
int in3 = 5;
int in4 = 6;

#define arr_size 5
String textArr[arr_size] = {"READY", "LEFT", "RIGHT", "DONE", "STOP"};
String incoming;

void setup() {
  // put your setup code here, to run once:
  Serial.begin(9600);
  servo.attach(2);
  myStepper.setSpeed(60);
  pinMode(in1, OUTPUT);
  pinMode(in2, OUTPUT);
  Serial.println("Arduino is Ready");
}

void loop() {
  // put your main code here, to run repeatedly:

  /* 
   *  Code for reading data using the Arduino 
   *  
  */
  if (Serial.available()) {
    // String coming in from the Pi
    incoming = Serial.readString();
    incoming.toLowerCase();

    // turn stepper motor counter clockwise
    if(incoming.indexOf("left2") >= 0) {
      for (pos = 0; pos >= 0; pos--) {
        servo.write(pos);
        delay(10);
        myStepper.step(-stepsPerRevolution * 2);
        delay(500);
      }
    } else if (incoming.indexOf("left") >= 0) {
      for (pos = 0; pos >= 0; pos--) {
        servo.write(pos);
        delay(10);
        myStepper.step(-stepsPerRevolution);
        delay(500);
      }
    }

    else if (incoming.indexOf("right2") >= 0) {
      for (pos = 0; pos <= 0; pos++) {
        servo.write(pos);
        delay(10);
        myStepper.step(stepsPerRevolution * 2);
        delay(500);
      }
    }

    // turn stepper motor clockwise
    else if(incoming.indexOf("right") >= 0) {
      for (pos = 0; pos <= 0; pos++) {
        servo.write(pos);
        delay(10);
        myStepper.step(stepsPerRevolution);
        delay(500);
      }
    }

    // dispense spice using DC motor
    else if(incoming.indexOf("dispense") >= 0) {
      // turn DC motor clockwise
      digitalWrite(in1, HIGH);
      digitalWrite(in2, LOW);
      digitalWrite(in3, LOW);
      digitalWrite(in4, LOW);
      // TODO: FIGURE OUT DELAY BASED ON AMOUNT OF SPICE NEEDED
      delay(2000);

      
      digitalWrite(in1, LOW);
      digitalWrite(in2, HIGH);
      digitalWrite(in3, LOW);
      digitalWrite(in4, LOW);
      delay(2000);

      digitalWrite(in1, LOW);
      digitalWrite(in2, LOW);
      digitalWrite(in3, HIGH);
      digitalWrite(in4, LOW);
      delay(2000);

      digitalWrite(in1, LOW);
      digitalWrite(in2, LOW);
      digitalWrite(in3, LOW);
      digitalWrite(in4, HIGH);
      delay(2000);
      
      // turn off dc motor once dispensing is done
      digitalWrite(in1, LOW);
      digitalWrite(in2, LOW);

      digitalWrite(in3, LOW);
      digitalWrite(in4, LOW);
    }

    else if(incoming.indexOf("1") >= 0) {
      digitalWrite(in1, HIGH);
      digitalWrite(in2, LOW);
      digitalWrite(in3, LOW);
      digitalWrite(in4, LOW);
      delay(2000);

      // turn off dc motor once dispensing is done
      digitalWrite(in1, LOW);
      digitalWrite(in2, LOW);

      digitalWrite(in3, LOW);
      digitalWrite(in4, LOW);
    }

    else if(incoming.indexOf("2") >= 0) {
      digitalWrite(in1, LOW);
      digitalWrite(in2, HIGH);
      digitalWrite(in3, LOW);
      digitalWrite(in4, LOW);
      delay(2000);

      // turn off dc motor once dispensing is done
      digitalWrite(in1, LOW);
      digitalWrite(in2, LOW);

      digitalWrite(in3, LOW);
      digitalWrite(in4, LOW);
    }

    else if(incoming.indexOf("3") >= 0) {
      digitalWrite(in1, LOW);
      digitalWrite(in2, LOW);
      digitalWrite(in3, HIGH);
      digitalWrite(in4, LOW);
      delay(2000);

      // turn off dc motor once dispensing is done
      digitalWrite(in1, LOW);
      digitalWrite(in2, LOW);

      digitalWrite(in3, LOW);
      digitalWrite(in4, LOW);
    }

    else if(incoming.indexOf("4") >= 0) {
      digitalWrite(in1, LOW);
      digitalWrite(in2, LOW);
      digitalWrite(in3, LOW);
      digitalWrite(in4, HIGH);
      delay(1500);
      
      // turn off dc motor once dispensing is done
      digitalWrite(in1, LOW);
      digitalWrite(in2, LOW);

      digitalWrite(in3, LOW);
      digitalWrite(in4, LOW);
    }
    
    // specified operation is done -> send DONE indicator to Pi
    Serial.println("DONE");
  }
}

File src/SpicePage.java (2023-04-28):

import java.util.ArrayList;
import java.util.Collections;
import java.util.List;
import javafx.application.Application;
import javafx.collections.FXCollections;
import javafx.collections.ObservableList;
import javafx.geometry.Pos;
import javafx.scene.Scene;
import javafx.scene.control.Button;
import javafx.scene.control.Label;
import javafx.scene.control.Slider;
import javafx.scene.control.TableColumn;
import javafx.scene.control.TableView;
import javafx.scene.control.cell.PropertyValueFactory;
import javafx.scene.image.Image;
import javafx.scene.image.ImageView;
import javafx.scene.layout.AnchorPane;
import javafx.scene.layout.BorderPane;
import javafx.scene.layout.HBox;
import javafx.scene.paint.Color;
import javafx.scene.text.Font;
import javafx.stage.Stage;
import javafx.stage.StageStyle;
 
public class SpicePage extends Application {
    private final TableView<spiceInfo> table = new TableView<>();
    TableView<spiceInfo> selectedSpiceTable = new TableView<>();
    private final ObservableList<spiceInfo> data = FXCollections.observableArrayList( // populate table
        new spiceInfo("Salt", 1, 0.0),
        new spiceInfo("Pepper", 2, 0.0),
        new spiceInfo("Garlic Powder", 3, 0.0),
        new spiceInfo("Garlic", 4, 0.0),
        new spiceInfo("Cinnamon", 5, 0.0),
        new spiceInfo("Paprika", 6, 0.0),
        new spiceInfo("Curry Powder", 7, 0.0),
        new spiceInfo("Turmeric", 8, 0.0)
    );
    ArrayList<spiceInfo> rows = new ArrayList<>();

    @Override
    public void start(Stage primaryStage) {
        ArrayList<TableColumn<spiceInfo, String>> columns = new ArrayList<>();
        
        TableColumn<spiceInfo, String> spiceCol = new TableColumn<>("Spice");
        spiceCol.setStyle("-fx-alignment: CENTER; -fx-font-size: 16px");
        spiceCol.setCellValueFactory(new PropertyValueFactory<>("Spice"));

        columns.add(spiceCol);

        table.getColumns().addAll(columns);

        table.setItems(data);
        table.setColumnResizePolicy(TableView.CONSTRAINED_RESIZE_POLICY);
        table.setPrefWidth(300);
        table.setPrefHeight(400);
        table.setStyle("-fx-font-size: 16px");

        BorderPane borderPane = new BorderPane();

        AnchorPane anchorPane = new AnchorPane();
        anchorPane.setStyle("-fx-background-color: #1c1f21;");
        anchorPane.getChildren().add(borderPane);

        AnchorPane.setTopAnchor(anchorPane, 0.0);
        AnchorPane.setLeftAnchor(anchorPane, 0.0);
        AnchorPane.setRightAnchor(anchorPane, 0.0);
        AnchorPane.setBottomAnchor(anchorPane, 0.0);

        Slider measurementSlider = new Slider(0, 10, 0);
        measurementSlider.setShowTickLabels(true);
        measurementSlider.setShowTickMarks(true);
        measurementSlider.setStyle("-fx-control-inner-background: #1c1f21; -fx-tick-label-fill: white; -fx-tick-mark-fill: white;");
        AnchorPane.setBottomAnchor(measurementSlider, 200.0); 
        AnchorPane.setLeftAnchor(measurementSlider, 140.0); 
        AnchorPane.setRightAnchor(measurementSlider, 140.0); 

        anchorPane.getChildren().add(measurementSlider);

        Label measurementDisplay = new Label();
        measurementDisplay.setText("Quantity: __ tsp");
        measurementDisplay.setTextFill(Color.WHITE);
        measurementDisplay.setFont(new Font("System Bold", 24.0));
        measurementDisplay.setMaxWidth(Double.MAX_VALUE);
        AnchorPane.setBottomAnchor(measurementDisplay, 150.0);
        AnchorPane.setLeftAnchor(measurementDisplay, 0.0);
        AnchorPane.setRightAnchor(measurementDisplay, 0.0);
        measurementDisplay.setAlignment(Pos.CENTER);
        measurementDisplay.setPrefWidth(358.0);
        measurementDisplay.setPrefHeight(40.0);

        anchorPane.getChildren().add(measurementDisplay);

        ArrayList<TableColumn<spiceInfo, String>> spiceColumn = new ArrayList<>();
        ArrayList<TableColumn<spiceInfo, Double>> quantityColumn = new ArrayList<>();
        
        TableColumn<spiceInfo, String> spiceColFinal = new TableColumn<>("Spice");
        spiceColFinal.setStyle("-fx-alignment: CENTER; -fx-font-size: 16px");
        spiceColFinal.setCellValueFactory(new PropertyValueFactory<>("Spice"));

        TableColumn<spiceInfo, Integer> mapCol = new TableColumn<>("Mapping");
        mapCol.setStyle("-fx-alignment: CENTER");
        mapCol.setCellValueFactory(new PropertyValueFactory<>("Mapping"));

        TableColumn<spiceInfo, Double> quantityCol = new TableColumn<>("Quantity");
        quantityCol.setStyle("-fx-alignment: CENTER; -fx-font-size: 16px");
        quantityCol.setCellValueFactory(new PropertyValueFactory<>("quantity"));

        spiceColumn.add(spiceColFinal);
        quantityColumn.add(quantityCol);

        selectedSpiceTable.getColumns().addAll(spiceColumn);
        selectedSpiceTable.getColumns().addAll(quantityColumn);

        selectedSpiceTable.setColumnResizePolicy(TableView.CONSTRAINED_RESIZE_POLICY);
        selectedSpiceTable.setPrefWidth(300);
        selectedSpiceTable.setPrefHeight(400);
        selectedSpiceTable.setStyle("-fx-font-size: 16px");

        Label spiceInstruction = new Label();
        spiceInstruction.setText("Choose spices below to dispense and measure the quantities for each in tsp.");
        spiceInstruction.setTextFill(Color.WHITE);
        spiceInstruction.setFont(new Font("System Bold", 20.0));
        spiceInstruction.setMaxWidth(Double.MAX_VALUE);
        AnchorPane.setLeftAnchor(spiceInstruction, 0.0);
        AnchorPane.setRightAnchor(spiceInstruction, 0.0);
        spiceInstruction.setAlignment(Pos.CENTER);
        spiceInstruction.setPrefWidth(358.0);
        spiceInstruction.setPrefHeight(80.0);

        anchorPane.getChildren().add(spiceInstruction);
        
        AnchorPane.setTopAnchor(borderPane, 120.0);
        AnchorPane.setLeftAnchor(borderPane, 160.0);
        AnchorPane.setRightAnchor(borderPane, 160.0);
        AnchorPane.setBottomAnchor(borderPane, 280.0);

        borderPane.setCenter(table);

        Button backButton = new Button("←"); // back button to go back to landing page
        backButton.setLayoutX(10);
        backButton.setLayoutY(anchorPane.getHeight() - backButton.getPrefHeight() - 10);
        backButton.setPrefWidth(100.0);
        backButton.setPrefHeight(100.0);
        backButton.setTextFill(Color.WHITE);
        backButton.setStyle("-fx-background-color: transparent; -fx-cursor: hand;");
        backButton.setFont(new Font("System Bold", 44.0));
        backButton.setOnAction(event -> {
            primaryStage.close();
            homeListener();
        });
        anchorPane.getChildren().add(backButton);

        anchorPane.widthProperty().addListener((obs, oldWidth, newWidth) -> {
            backButton.setLayoutX(10);
        });
        
        anchorPane.heightProperty().addListener((obs, oldHeight, newHeight) -> {
            backButton.setLayoutY(newHeight.doubleValue() - backButton.getPrefHeight() - 10);
        });
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

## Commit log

2023-03-04 Added model for motor
    [motor.ipt]
2023-03-04 Added model for bearing table
    [bearing_table.ipt]
2023-03-05 Finished frontend for landing page
2023-03-06 Added back buttons, basic layout for spice page
2023-03-08 Added measurement slider, arrows for back buttons
2023-03-14 DC Motor Assembly
    Added DC Motor model
    [DCMotor.ipt, DCMotorAssembly.0001.iam, DCMotorAssembly.iam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]
2023-03-21 Added Spice Container
    Tube
    [FiestaSpiceContainer.ipt]
2023-03-23 Adding Base and Assembly
    Added base and a few components, first version of overall assembly
    [BaseAssemblyMk1.0016.iam, BaseAssemblyMk1.iam, BaseMk1.0002.ipt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]
2023-04-03 Update and rename testing.ino to motor_control.ino
2023-04-05 Bearing Gears and Housing Fixes
    Added new gears for bearing table and stepper motor. Also changed housing... continuing to work on lid
    [BearingGearMK1.ipt, BearingGearMk2.0010.ipt, BearingGearMk2.ipt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]
2023-04-12 Updated parts
    Motor Gear, New Lid, New Housing
    [Assembly1.0002.iam, Assembly1.iam, BearingGearMk2.0010.ipt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]
2023-04-12 Added Connector
    [Connector.0001.ipt, Connector.ipt, Connector.stl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]
2023-04-20 Design adjustments for landing page
2023-04-21 Add files via upload
    20kg servo control for Arduino.
2023-04-24 Add files via upload
    Combined all motor control code into 1 file.
2023-04-24 Fixed spice table bug
    [SpicePage.java]
